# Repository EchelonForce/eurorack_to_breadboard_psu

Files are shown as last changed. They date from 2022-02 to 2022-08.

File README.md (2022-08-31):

# Eurorack Bread Board Power Supply

This is a PCB for a bread board power supply for eurorack synthesizer development.

Full writeup here: https://www.robotdialogs.com/2022/08/breakout-boards-for-synthesizer.html

This work is licensed under a Creative Commons Attribution-NonCommercial-ShareAlike 4.0 International License. https://creativecommons.org/licenses/by-nc-sa/4.0/

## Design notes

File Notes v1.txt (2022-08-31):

v1 pcb panelized was under 60mm wide which is under the limit for 
Seeed's v-cut operation. Had them add margin, we'll see what that means.

V1  Assembly Notes
Resistors (R1 and R2) would be better on the bottom. It's hard to reach them if there's an issue on the top.

Assembly Order:
R1 and R2 Surface Mount
C1, C3, LEDs and Diodes
C2 and C4
Ferrites
2x5 Header
2x4 Headers

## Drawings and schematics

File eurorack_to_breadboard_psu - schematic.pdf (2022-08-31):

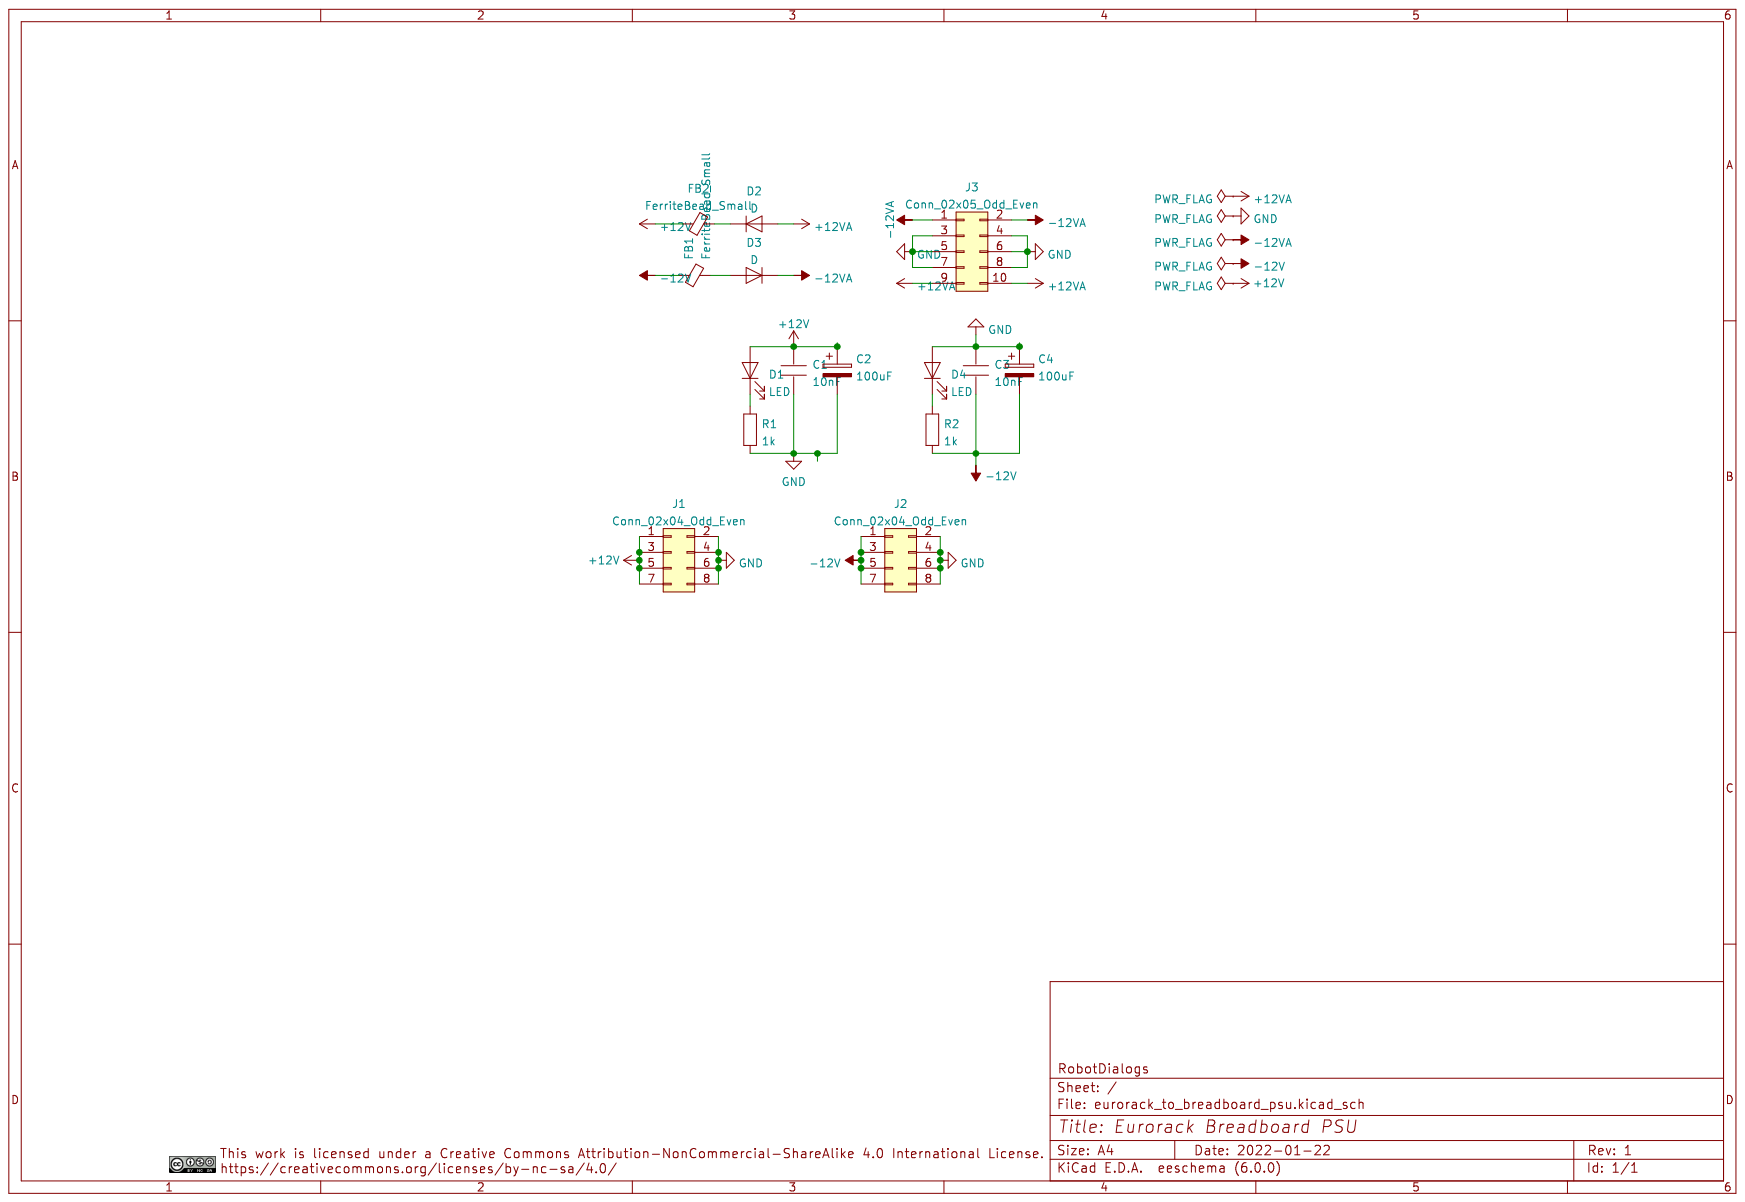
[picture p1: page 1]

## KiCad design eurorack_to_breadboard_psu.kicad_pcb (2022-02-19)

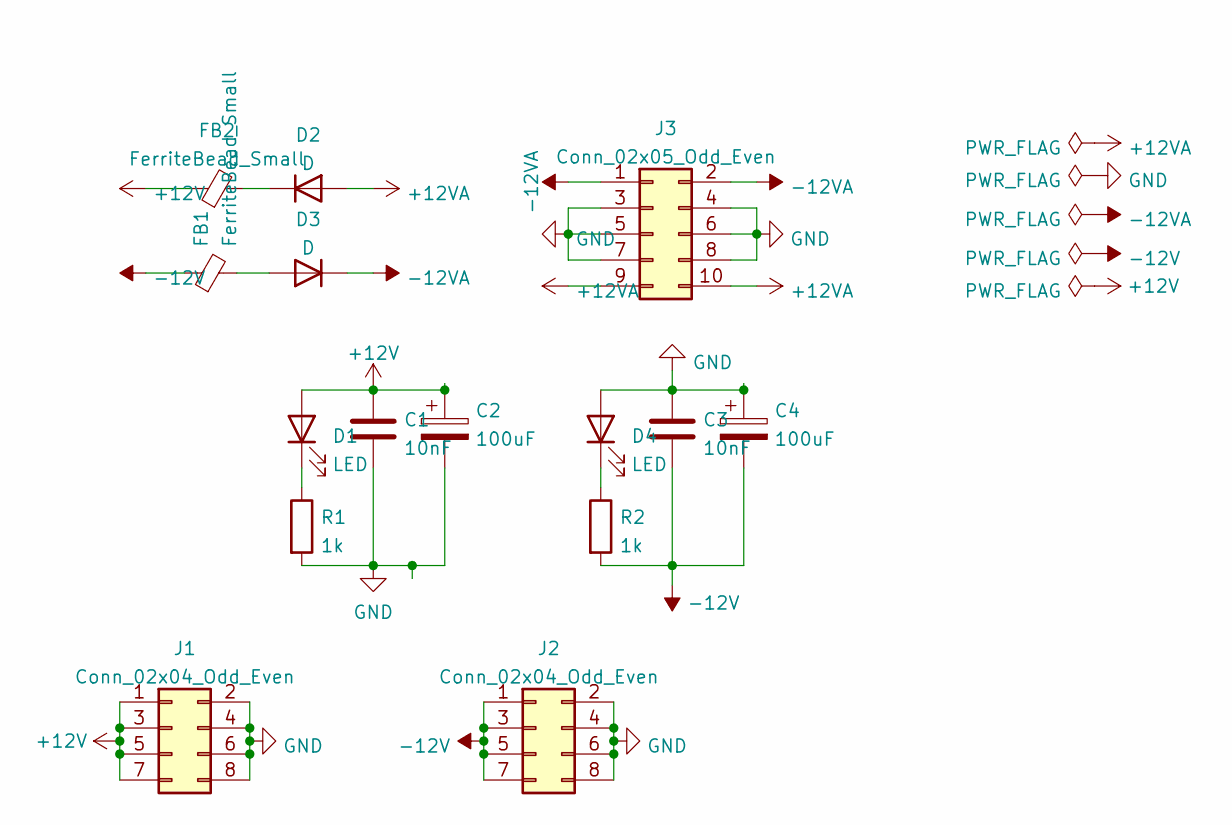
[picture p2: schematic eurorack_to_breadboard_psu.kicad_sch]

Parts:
C1, C3: 10nF; C_Disc_D5.1mm_W3.2mm_P5.00mm
C2, C4: 100uF; CP_Radial_D5.0mm_P2.50mm
D1, D4: LED; LED_D3.0mm
D2, D3: D; D_DO-15_P3.81mm_Vertical_KathodeUp
FB1, FB2: FerriteBead_Small; L_Axial_L9.5mm_D4.0mm_P5.08mm_Vertical_Fastron_SMCC
J1, J2: Conn_02x04_Odd_Even; PinHeader_2x04_P2.54mm_Vertical
J3: Conn_02x05_Odd_Even; IDC-Header_2x05_P2.54mm_Vertical
R1, R2: 1k; R_1206_3216Metric_Pad1.30x1.75mm_HandSolder

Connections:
+12V: C1.1, C2.1, D1.2 (A), FB2.1, J1.1, J1.3, J1.5, J1.7
+12VA: D2.2 (A), J3.9, J3.10
-12V: C3.2, C4.2, FB1.1, J2.1, J2.3, J2.5, J2.7, R2.2
-12VA: D3.1 (K), J3.1, J3.2
GND: C1.2, C2.2, C3.1, C4.1, D4.2 (A), J1.2, J1.4, J1.6, J1.8, J2.2, J2.4, J2.6, J2.8, J3.3, J3.4, J3.5, J3.6, J3.7, J3.8, R1.2
unnamed: D1.1 (K), R1.1
unnamed: D2.1 (K), FB2.2
unnamed: D3.2 (A), FB1.2
unnamed: D4.1 (K), R2.1

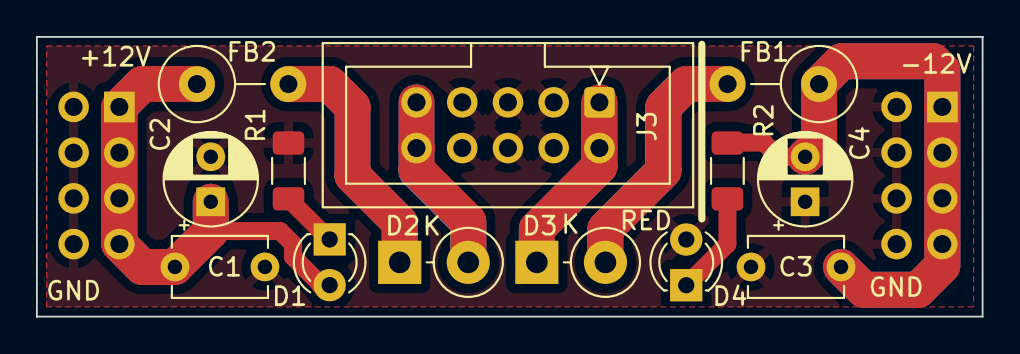
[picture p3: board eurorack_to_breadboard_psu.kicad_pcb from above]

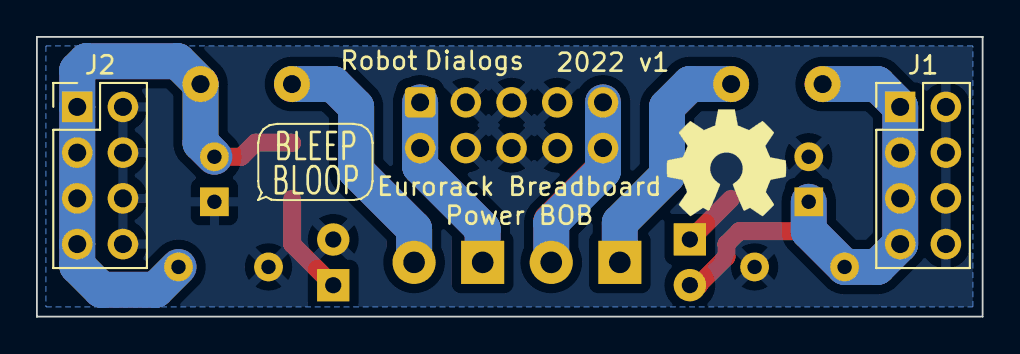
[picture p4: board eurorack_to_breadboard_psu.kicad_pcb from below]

Board: 2 copper layers, 52.5 x 15.5 mm, 15 parts (2 on the bottom side), 9 nets.

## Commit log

2022-02-19 Version 1 PCB as ordered
    [eurorack_to_breadboard_psu.kicad_pcb, eurorack_to_breadboard_psu.kicad_sch, eurorack_to_breadboard_psu_panelized.kicad_pcb]
2022-08-31 Notes on v1 boards
2022-08-31 Fix page labels and add schematic pdf
    [eurorack_to_breadboard_psu.kicad_sch]
